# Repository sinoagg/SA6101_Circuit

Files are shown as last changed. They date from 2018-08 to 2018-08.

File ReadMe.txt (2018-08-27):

transistor tester V1.07_E3
08/28/2017
更新内容
1.适配九院新的大机箱，调整连接器位置和LED灯位置

transistor tester V1.07_E2
08/28/2017
更新内容
1.增加一路串口，用来与温控器连接控制小气室的温度。
2.将全部PGA的数字引脚取消，只用它的电压抬升功能。
3.修改了原来的引线错误。

transistor tester V1.07_E1
07/13/2017
更新内容
1.调整DB9接口位置，使USB和下载器接口能漏到后面板表面。
2.在ADA4530后增加一个1K电阻到地，增加小电流泄露途径，快速使测量电压到达预定值。
3.增大定位孔径，方便准确定位。
4.修改R99，R101为空，R100为120欧，以实现正常485通信。
5.将电压输出的与51K并联的电容从100nF调整到100pF,从而增加带宽，使电压更迅速到位。

transistor tester V1.07
06/30/2017
更新内容
1.将源漏基极输出端各加上一个继电器，在仪器刚上电时，会输出24V 1到2秒钟，导致一些器件被击穿。继电器先断开，待设备稳定后再连接。
2.AD8253的写入选择引脚加上一些0欧电阻进行选择，默认情况下不进行放大，以减少带来的干扰。

transistor tester V1.06
05/05/2017
更新内容
1.将ADA4530错误的5V没连接修正
2.将ADA4530输出端的10欧电阻调整为0欧，但对PCB无影响
3.调整定位孔尺寸
4.增加LCD显示屏连接器，将串口3用来和显示屏通信

transistor tester V1.05_E1
03/15/2017
更新内容
1.将核心运放AD4522-2改成ADA5430，降低偏置电流，降低输入电流噪声密度
2.将第二级运放反向运放去掉，降低噪声；换成一个仪用放大器，增益可调
3.AD7988的驱动引脚由于布线原因有变化

transistor tester V1.05_E0
03/04/2017
更新内容
1.修改上一版中AD7721AIN-连接到地的错误，正确需连接到2.5V。
2.暂时不增加大电流输出功能

transistor tester V1.05
01/09/2016
更新内容
1.在4个输出端连到ADC输入，监测输出电压。
2.上一版本中源级负压出现失真的现象，即源级的反向输入端电压与正向输入端不同。此版本未解决。
3.调整四个输出端的最后一级电路，增加GUARD输出，连接器选为3同轴电缆。

transistor tester V1.04
12/12/2016
更新内容
1.将调整档位的74LS145除去，因为其输出常态为高电平，只有一路为低电平，正好与所需内容相反。

transistor tester V1.03
12/03/2016
更新内容
1.将DAC芯片AD5687R的SPI接口上的排阻去掉，否则影响通信
2.增加更多档位，最高反馈电阻为10G欧姆以测量更小电流。
3.调整结构尺寸适配外壳。

transistor tester V1.02
10/21/2016
更新内容：
1.更新继电器换挡控制
2.增加源级电压控制功能
3.使用独立的ADC去进行测量，提高精度
4.使用独立的DAC去输出，提高精度

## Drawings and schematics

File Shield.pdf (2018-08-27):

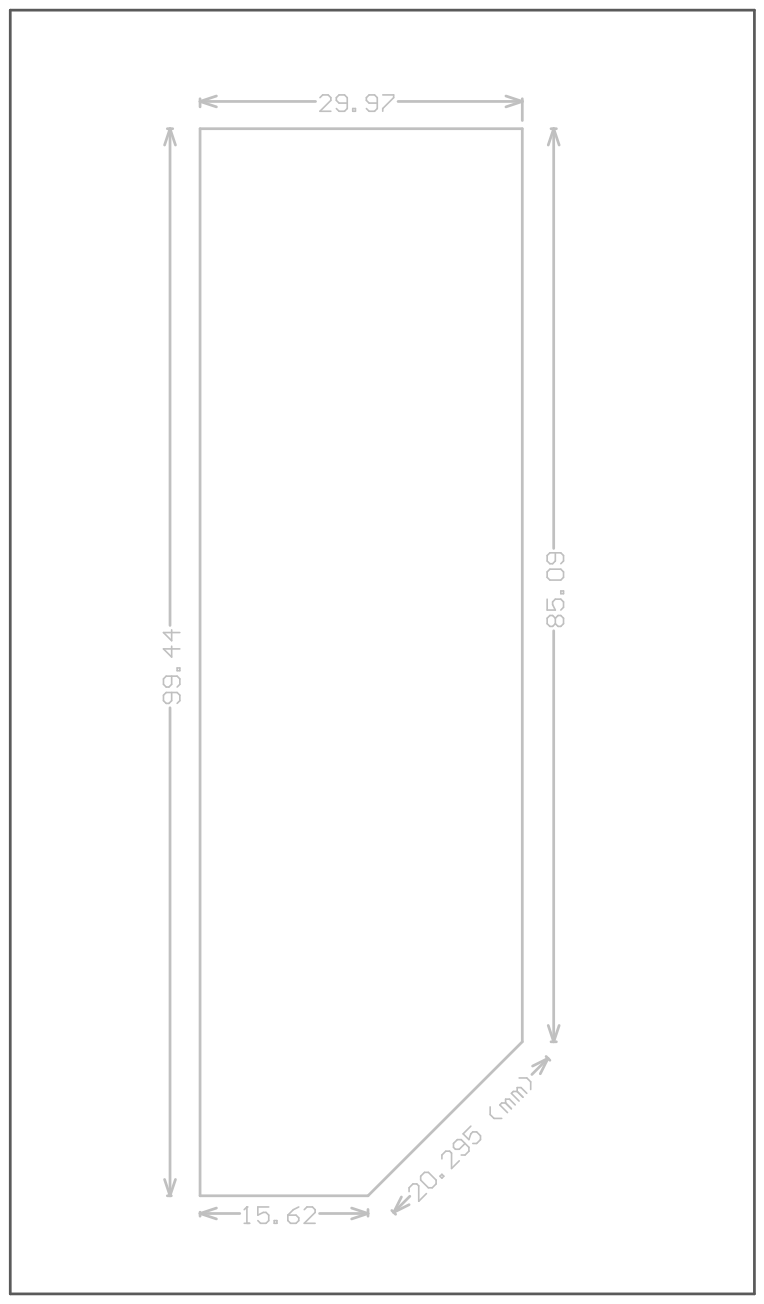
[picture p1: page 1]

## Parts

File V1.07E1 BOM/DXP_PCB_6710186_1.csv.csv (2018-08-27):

Comment | Description | Designator | Footprint | LibRef | Pins | Quantity
100nF | Capacitor | C1, C2, C3, C4, C5, C29, C71, C72, C73, C74, C75, C76, C78, C79, C82, C86, C89 | 603 | Cap | 2 | 17
1uF | Capacitor | C6, C22 | 603 | Cap | 2 | 2
22nF | Capacitor | C21, C80 | 603 | Cap | 2 | 2
100nF | Capacitor, Capacitor, Capacitor, Capacitor, Capacitor, Capacitor, Capacitor, Capacitor, Capacitor, Capacitor, Capacitor,100V, Capacitor,100V, Capacitor, Capacitor, Capacitor, Capacitor, Capacitor, Capacitor, Capacitor, Capacitor, Capacitor, Capacitor, Capacitor,100V, Capacitor,100V, Capacitor, Capacitor, Capacitor, Capacitor, Capacitor, Capacitor, Capacitor, Capacitor, Capacitor,100V, Capacitor,100V, Capacitor, Capacitor, Capacitor, Capacitor, Capacitor,100V, Capacitor,100V, Capacitor, Capacitor, Capacitor, Capacitor, Capacitor,100V, Capacitor,100V | C30, C31, C33, C34, C36, C42, C44, C46, C48, C50, C57, C77, C83, C84, C85, C91, C92, C110, C112, C114, C116, C118, C120, C122, C124, C126, C129, C130, C132, C134, C136, C137, C139, C140, C143, C145, C147, C148, C150, C151, C153, C155, C157, C160, C162, C163 | 805 | Cap | 2 | 46
10uF | Polarized Capacitor (Radial) | C32, C35, C37, C43, C45, C47, C49, C51, C55, C59, C60, C113 | 6032_POL | Cap Pol1 | 2 | 12
100pF | Capacitor | C38, C39, C40, C41, C104 | 805 | Cap | 2 | 5
47uF | Polarized Capacitor (Radial) | C52, C53 | cap_pol_8*10.2 | Cap Pol1 | 2 | 2
47uF,50V | Polarized Capacitor (Radial) | C54, C61 | cap_pol_8*10.2 | Cap Pol1 | 2 | 2
1uF | Capacitor,100V, Capacitor, Capacitor,100V | C56, C58, C62 | 805 | Cap | 2 | 3
47pF | Capacitor | C63 | 805 | Cap | 2 | 1
10pF | Capacitor | C64 | 805 | Cap | 2 | 1
4.7pF | Capacitor | C65 | 805 | Cap | 2 | 1
1pF | Capacitor | C66 | 805 | Cap | 2 | 1
10uF | Capacitor | C90 | 805 | Cap | 2 | 1
0.47pF | Capacitor | C100 | 805 | Cap | 2 | 1
NULL | Capacitor | C101, C102, C103 | 805 | Cap | 2 | 3
10uF | Polarized Capacitor (Radial) | C111, C115, C117 | 6032_POL | Cap Pol1 | 2 | 3
10nF | Capacitor | C128, C142, C158, C159 | 603 | Cap | 2 | 4
1nF | Capacitor,100V | C131, C138, C149, C161 | 603 | Cap | 2 | 4
USB_5pin |  | DL | USBmicro_B | USB_5pin | 5 | 1
SMA | BNC Elbow Connector | DRAIN, GATE, SOURCE, SUB | SMA_SMT | BNC | 2 | 4
USART | Receptacle Assembly, 9 Position, Right Angle | J1 | DSUB1.385-2H9 | D Connector 9 | 11 | 1
Relay | Relay OMRON | K1, K2, K3, K4, K9, K10, K11, K12, K13, K14, K15, K16, K17 | Relay_OMRON5V | Relay_OMRON5V | 6 | 13
AXICOM IM |  | K18, K19, K20 | AXICOM_IM06 | AXiCOM IM05 | 8 | 3
10uH | Inductor | L1 | 805 | Inductor | 2 | 1
Bead | Inductor | L2 | 8040 | Inductor | 2 | 1
10uH | Inductor | L3 | 1206 | Inductor | 2 | 1
Header 8 | Header, 8-Pin | LCD | HDR1X8 | Header 8 | 8 | 1
Header 3 | Header, 3-Pin | LED | HDR1X3 | Header 3 | 3 | 1
Header 3 | Header, 3-Pin | PWR_5V, PWR_20V | PWR_3T | Header 3 | 3 | 2
NUD3112 | Relay Driver 5V Supply | Q1, Q2, Q3, Q4, Q9, Q10, Q11, Q12, Q13, Q14, Q15, Q16, Q17, Q18, Q19, Q20 | SOT-23 | NUD3105 | 3 | 16
100R | Resistor | R1, R13 | 603 | Res1 | 2 | 2
10K | Resistor | R2 | 603 | Res1 | 2 | 1
Res1 | Resistor | R4, R5, R6, R47, R48, R49, R50 | 805 | Res1 | 2 | 7
100K | Resistor | R7 | 805 | Res1 | 2 | 1
0R | Resistor | R8, R90, R94, R95, R96 | 603 | Res1 | 2 | 5
1K | Resistor | R9, R61, R62, R63, R64, R65, R68, R69, R70, R71, R72, R75, R76, R77, R78, R79, R82, R83, R84, R85, R86 | 603 | Res1 | 2 | 21
5.1K | Resistor | R14, R16, R18, R21, R22, R24, R34, R36 | 805 | Res1 | 2 | 8
51K | Resistor | R15, R17, R19, R20, R23, R25, R35, R37 | 805 | Res1 | 2 | 8
22R | Resistor | R40, R41 | 402 | Res1 | 2 | 2
1.5K | Resistor | R42 | 402 | Res1 | 2 | 1
1M | Resistor | R46 | 805 | Res1 | 2 | 1
9.1K | Resistor | R60, R67, R74, R81 | 603 | Res1 | 2 | 4
2.2K | Resistor | R66, R73, R80, R87 | 603 | Res1 | 2 | 4
Res1 | Resistor | R91 | 603 | Res1 | 2 | 1
NULL | Resistor | R92, R93, R97, R101, R102 | 603 | Res1 | 2 | 5
120R | Resistor | R100 | 603 | Res1 | 2 | 1
STM32F103RET6 | STM32 ARM-based 32-bit MCU with 128 Kbytes Flash, 64-pin LQFP, Industrial Temperature | U1 | LQFP64_N | STM32F103RBT6 | 64 | 1
RT9193 |  | U2 | SOT-23-5 | RT9193 | 5 | 1
AD5687R |  | U3, U4 | TSSOP16 | AD5687R | 16 | 2
ADR441 | Ultralow Noise, XFET Voltage References | U5, U19 | SO-8N | ADR441 | 8 | 2
AD8601 | Precision CMOS, Single Supply, Rail to Rail, Windband Operational Amplifiers | U6, U26 | SOT-23-5 | AD8601 | 5 | 2
AD7988-1 |  | U7 | MSOP10 | AD7988-1 | 10 | 1
AD8253 |  | U8 | RM-10 | AD8253 | 10 | 1
ADR127-1.25 |  | U9 | SOT_UJ6 | ADR127 | 6 | 1
ADA4522-2 |  | U22, U23, U29, U30, U32, U35, U38, U41 | SO-8N | AD8676 | 8 | 8
ADA5430 |  | U24 | SO-8N | ADA5430 | 8 | 1
AD4522-1 |  | U33, U36, U39, U42 | SO-8N | OP27 | 8 | 4
AD7791 | One channel 24 bits ADC | U34, U37, U40, U43 | RM-10 | AD7791 | 10 | 4
SP3485 |  | U44 | SO-8N | SP3485 | 8 | 1
USB | USB interface | USB | USB_A | USB_Normal | 6 | 1
8M smd |  | X1 | 8Mhz_XTAL | 8M smd | 3 | 1
